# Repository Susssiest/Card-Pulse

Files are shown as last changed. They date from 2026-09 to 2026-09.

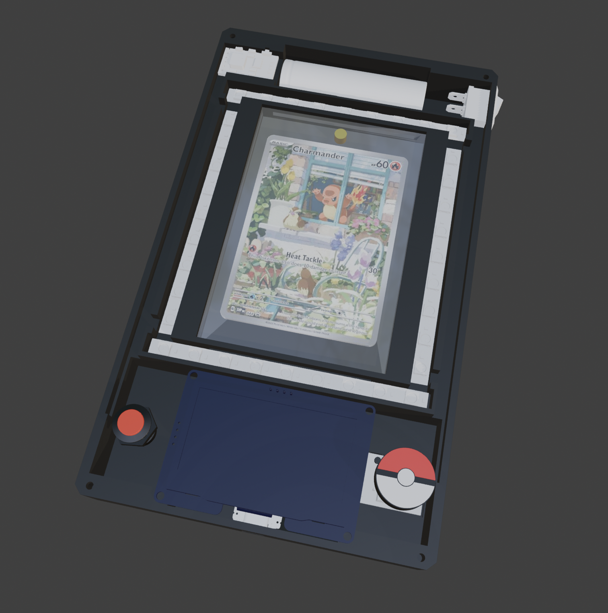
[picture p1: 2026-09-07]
Renders/V2 Internals.png

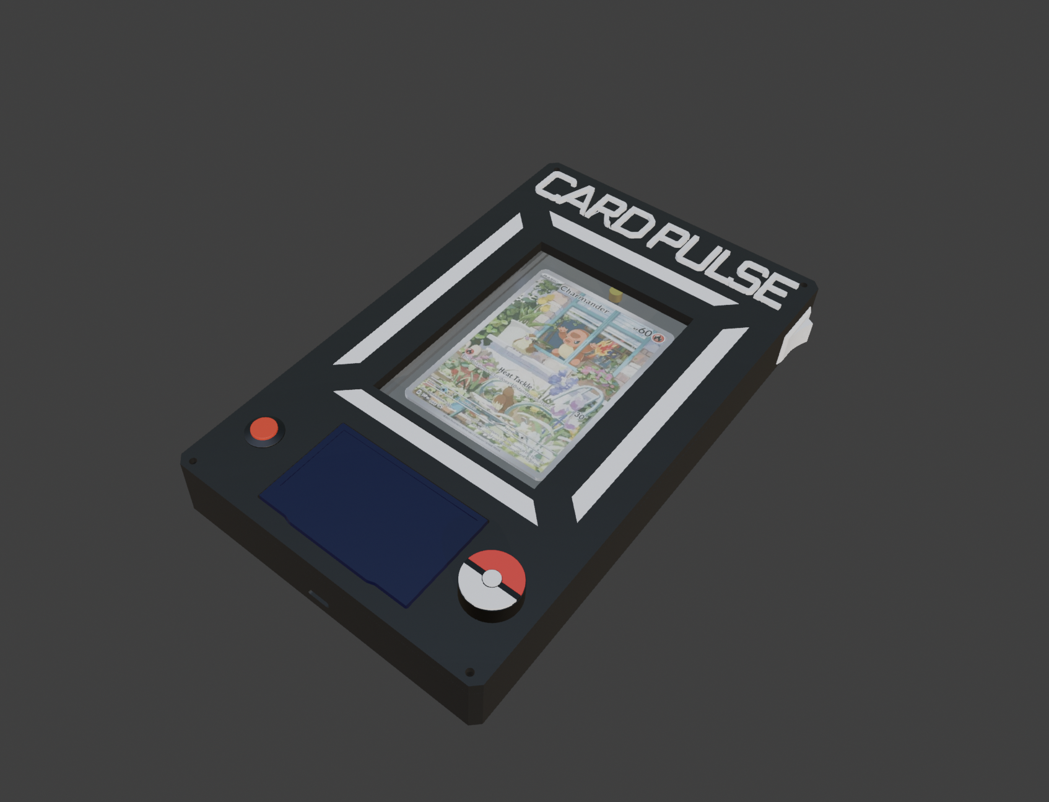
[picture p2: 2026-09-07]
Renders/V2 Render.png

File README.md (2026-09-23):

# Card Pulse

Render

  A little TCG display that can hold a card in a slab that includes a screen to display the value of the card, and a rotary encoder and momentary push button to control the screen. Ws2812bs surround the card in a rectangular frame to surround the card with a underglow and light some transparent filament on the front cover.

## Case Summary

  The card will be inserted into a protective 35pt Toploader, and inserted into the base shell, and then held in place by the top lid, which is screwed in to the base via m3*12 self tapping screws. The case has many different paths and spaces for the different parts: The LEDs have a rectangular cutout around the card, with small holes in the wall separating them to make a underglow effect, but will be also facing upwards, into 3D printed diffusers to have status leds in the lid. The LEDs will have their own control panel/ menu. LEDs will be looped together into one din, gnd, and 5v. The case has a second rectangular hole surrounding the leds, I’m planning on putting all the battery and led wires in it (the battery is above the leds, and therefore the leds are in between the battery and xiao).The wire paths will have an occasional hole in the intersecting wall to provide holes for wires to come through. The card also has a space for a battery, already mentioned above, it sits at the top of the case. It has a space next to it for the 5V boost for leds, and it has a slot to the other side for the power switch.

## Complete List of Parts

1. ESP32S3
2. KY040
3. 12 mm Momentary Push Button
4. 18650 3.7 V Lithium battery
5. 2.42 in Oled Screen
6. 74AHCT14 Level Shifter
7. 5V Boost
8. KCD01
9. Resistor: 330 R
10. Capacitor: 1000uf
11. Capacitor: 0.1uf
12. 22 AWG Wire
13. 26 AWG Wire
14. JST Connectors

## BOM

Screenshot 2026-09-07 at 10 22 27 AM

## Wiring Diagram

Screenshot 2026-09-07 at 10 07 12 AM

## Assembly

https://github.com/user-attachments/assets/116129a6-97be-465f-80bf-904350856c0c

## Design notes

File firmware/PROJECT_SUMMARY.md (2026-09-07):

# CardFrame — Project Summary

## What this is

CardFrame is a battery-powered, Wi-Fi-connected desk display for a single
trading card at a time. It shows the card's name, set/number/variant, and
current market price, plots a price-history graph, and drives an addressable
LED strip for ambient lighting/effects around the frame. All navigation is
done with a rotary encoder (scroll/adjust) and a separate physical button
(select/confirm), with an on-screen keyboard for any text entry (Wi-Fi
passwords, card search). Card and pricing data comes from
[tcgapi.dev](https://tcgapi.dev); when Wi-Fi or the API is unavailable, the
frame falls back to the last cached price or clearly-labeled demo data so it
never freezes or lies about what it's showing.

## Goals

- Run on an ESP32-S3, flashed over its native USB-C port from the Arduino IDE.
- Organize the firmware as a clean, well-commented, modular Arduino sketch
  that's easy to extend later (new screens, a different display, a second
  data source, etc.).
- Make every screen navigable with exactly two physical controls: a KY-040
  rotary encoder (scroll / adjust value) and a separate 12mm momentary push
  button (select / confirm / back). The encoder's own built-in push switch is
  intentionally never used.
- Keep the UI responsive at all times — input, LED animation, and Wi-Fi
  housekeeping all use `millis()`-based non-blocking code, with the one
  unavoidable exception of the tcgapi.dev HTTP calls themselves (bounded to
  an 8-second timeout, triggered only at specific user-initiated moments —
  see `CardFrame.ino`'s top comment for the full rationale).
- Be honest about data provenance: every price and every graph is tagged as
  Live, Cached, or Demo, and the UI never presents mock numbers as real
  market data.

## Core user-facing behavior

**Home screen** — shows the selected card's name, set/number/variant, price,
and last-updated/data-source indicator; a Wi-Fi status icon, an LED-settings
icon, and a card-library icon; and a 7-day (default) price-history graph.
Rotating the encoder moves a highlight between the three icons and the
graph; pressing the button opens whichever is highlighted.

**Card library** — a scrollable list of saved cards plus "Add Card",
"Remove Card" (with a Yes/No confirmation screen), and "Back". Selecting a
card makes it current, returns Home, and refreshes its data.

**Add a card** — an on-screen keyboard (rotary-encoder driven, wraps between
character rows) for typing a search query, which is sent to tcgapi.dev;
results are shown as a scrollable list to pick from and add to the library.
Network errors, empty results, and rate limits are shown as a message
instead of freezing the device.

**Wi-Fi setup** — scans and lists nearby networks, lets you select one and
type its password on the same on-screen keyboard (masked as dots), and shows
connecting/success/failure without blocking the rest of the firmware.
Credentials are saved so the frame reconnects automatically after that.

**Graph settings** — switch the price-history range between 1 day, 7 days,
30 days, 90 days, and 1 year.

**LED settings** — power on/off, brightness, a color, an effect (Solid,
Rainbow, Color Wipe, Breathing, Off), and effect speed, for the WS2812B
strip.

**Offline/demo mode** — if Wi-Fi or tcgapi.dev is unavailable, or a specific
endpoint's response can't be parsed, the frame shows the last cached price
(if any) or a clearly-labeled synthetic "Demo Data"/"Demo History" value
instead of failing silently or showing something misleading.

## Hardware (bill of materials)

| # | Part | Role | Qty |
|---|---|---|-----|
| 1 | ESP32-S3 | Microcontroller, USB-C programming | 1 |
| 2 | WS2812B | Addressable LED strip | 1 |
| 3 | 3.7V 18650 Li-ion | Battery | 1 |
| 4 | MC242GX | 128x64 SSD1309 OLED display, I2C | 1 |
| 5 | KY-040 | Rotary encoder (CLK/DT only; built-in switch unused) | 1 |
| 6 | SW_Push | 12mm momentary push button | 1 |
| 7 | KCD01 | SPST power switch | 1 |
| 8 | (5V boost converter) | Steps battery voltage up to a regulated 5V rail | 1 |
| 9 | 74AHCT14 | Logic-level shifter/buffer for WS2812B data | 1 |
| 10 | 1000µF capacitor | Bulk capacitor on the LED power rail | 1 |
| 11 | 330Ω resistor | Series resistor on the WS2812B data line | 1 |
| 12 | Wire connector kit | General wiring/connectors | 1 |

Full wiring table, power diagram, and the exact 74AHCT14 pin-by-pin plan are
in `README.md`.

## Software architecture

The sketch is split into one file per concern so each piece can be modified,
tested, or swapped independently:

- `CardFrame.ino` — setup()/loop(), the master UI state machine, and the
  handful of moments a blocking tcgapi.dev call is allowed to happen.
- `Types.h` — shared structs/enums (`CardData`, `PriceData`, `UIState`, ...).
- `Config.h` — every pin, timing constant, display setting, and tcgapi.dev
  endpoint/auth placeholder, all in one place.
- `InputManager` — debounced rotary-encoder and button reading.
- `DisplayUI` — the U8g2 display driver plus every screen's drawing and
  navigation logic.
- `Keyboard` — the reusable on-screen keyboard widget (search text and
  masked Wi-Fi passwords both use it).
- `CardLibrary` — saved-card storage (NVS-backed), deliberately decoupled
  from the API and UI so it can later be swapped for SD-card storage, a web
  interface, or cloud sync.
- `WiFiManager` — non-blocking scan/connect state machine wrapping
  ESP32 `WiFi.h`.
- `TcgApiClient` — all HTTPS calls to tcgapi.dev, isolated so its exact
  endpoints/response fields can be updated later without touching any UI
  code. Endpoints whose response schema isn't publicly documented are marked
  `ADAPTER/TODO` and fall back to mock data rather than crashing.
- `LedController` — WS2812B/FastLED driver with non-blocking animation.
- `MockData` — hard-coded demo cards and deterministic mock price/graph
  generators, used both as the initial library seed and as the final
  fallback when the network and cache both come up empty.

## What still needs to be confirmed

The exact `tcgapi.dev` response field names for card details, current price,
and price history are not publicly documented (only `/v1/search` has a
published example response) — those calls are implemented against the
documented paths and authentication, but their JSON parsing is written as an
adapter that tries a couple of plausible field names and falls back to mock
data if the shape doesn't match, so the firmware always compiles and runs
even before those details are pinned down. See the assumptions list in
`README.md` for the complete set of things to double-check before finalizing
pin mapping and the display driver.

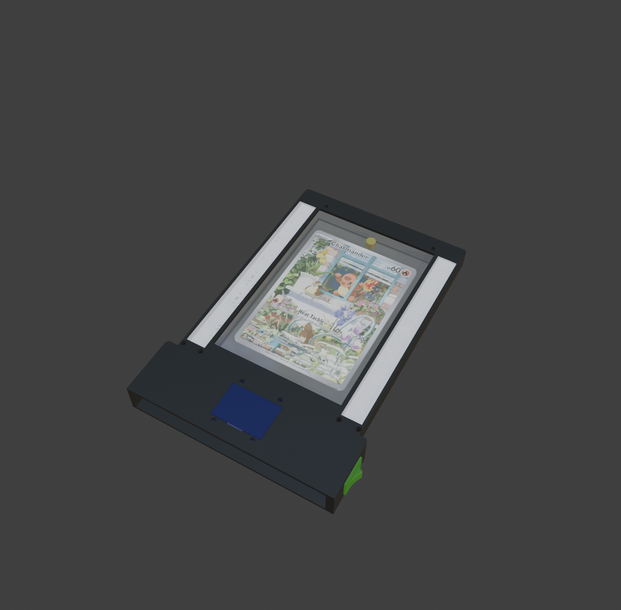
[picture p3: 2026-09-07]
Renders/V1 Render.png

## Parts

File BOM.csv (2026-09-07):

Item | Part Number | Description | Quantity (PART) | Prices | Notes | Seller | LINK | Total
1 | ESP32S3 | Microcontroller | 1 | $16.99 | ESP32S3 specifically | AMAZON | https://www.amazon.com/ESP32S3-2-4GHz-Dual-core-Supported-Efficiency-Interface/dp/B0BYSB66S5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 | $84.16
2 | 3.7V18650 | Battery | 1 | $11.72 | wired | AMAZON | Amazon.com: XINLANTECH 3.7V 2600mAh 18650 Rechargeable Li-ion Battery with Jst XH2.54/2P Connector Plug Wires for DIY Electronics, Toys, Lighting,Bluetooth Devices and More : Health & Household
4 | N.A | Capacitor Kit | 1 | $9.99 |  | AMAZON | https://www.amazon.com/ALLECIN-Electrolytic-Capacitor-Assortment-Kit/dp/B0C1VBXCQM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
5 | N/A | Wire Connectors Kit | 1 | $9.99 |  | AMAZON | https://www.amazon.com/Taiss-Connector-Housing-Connectors-F-066-580PCS/dp/B0BHT1FQGY
6 | SKU:MC242GX | Screen | 1 | $7.56 | white | AMAZON | https://www.aliexpress.us/item/2255799816264653.html?curPageLogUid=IFZZanUI4FB5
7 | KY040 | Rotary Encoder | 1 | $1.34 |  | ALI EXPRESS | https://www.aliexpress.us/item/3256805874306729.html?curPageLogUid=dIarbOQrocIS
8 | SW_Push | 12mm Momentary Push Button | 1 | $1.25 | red | ALI EXPRESS | https://www.aliexpress.us/item/3256804314578211.html?curPageLogUid=THWkP4Y0HGia
9 | KCD01 | SPST Switch | 1 | $1.98 | red | ALI EXPRESS | https://www.aliexpress.us/item/3256804169767079.html?curPageLogUid=kfSuK7F9Npq4
10 | N/A | 5V Boost | 1 | $1.45 |  | ALI EXPRESS | https://www.aliexpress.us/item/3256812360325771.html?curPageLogUid=Ue7Sb1GEffMK
11 | SN74AHCT125N | Level Shifter | 1 | $2.41 |  | ALI EXPRESS | https://www.aliexpress.us/item/3256807469514168.html?curPageLogUid=zjFDIzLuRHGn
12 | N/A | Wire Connectors Kit | 1 | $14.98 |  | ALI EXPRESS | https://www.amazon.com/XALXMAW-Connectors-Splicing-Connector-Stranded/dp/B0B28GQVVG
13 | 22 AWG | Wire: POWER | 1 | $2.60 | RED 10 meters | ALI EXPRESS | https://www.aliexpress.us/item/3256807355811935.html?curPageLogUid=Z52RvaM1nH8V
14 | 26 AWG | WIre: STANDARD | 1 | $1.90 | BLACK 10 meters | ALI EXPRESS | https://www.aliexpress.us/item/3256807355811935.html?curPageLogUid=Z52RvaM1nH8V
15 | R:330 Ω | Resistors | 1 | N/A | DO NOT NEED TO BUY | N/A | https://www.amazon.com/ALLECIN-Values-Resistor-Resistors-Assortment/dp/B0BTP6WYH1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
16 | WS2812B | WS2812B Strip | 1 | N/A | DO NOT NEED TO BUY | N/A | https://www.amazon.com/BTF-LIGHTING-Individual-Addressable-300Pixels-Non-Waterproof/dp/B088BPGMXB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

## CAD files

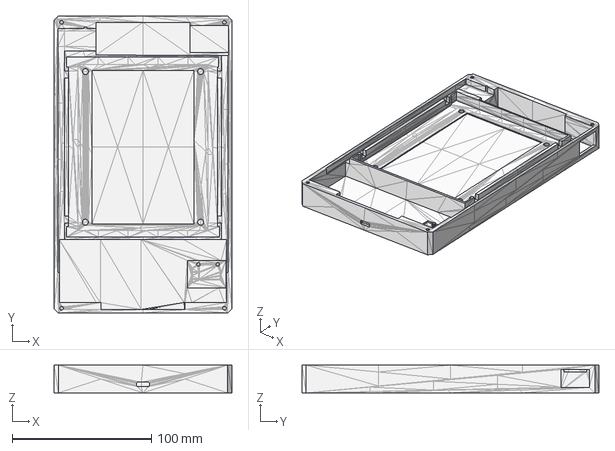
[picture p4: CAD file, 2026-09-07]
CAD/Prints/Main_Shell.step
127.4 x 213.0 x 20.0 mm

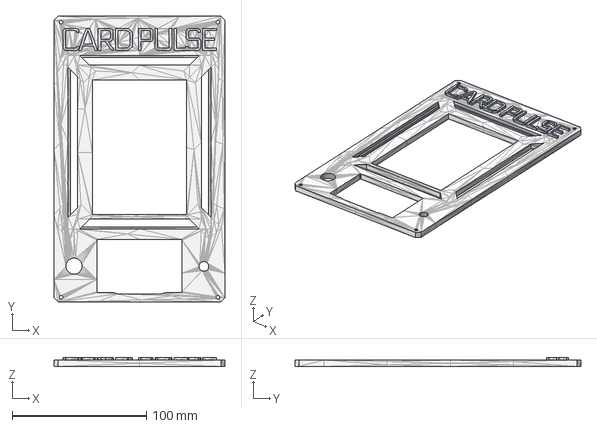
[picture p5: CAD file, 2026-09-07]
CAD/Prints/Card_Lid.step
127.4 x 213.0 x 6.62 mm

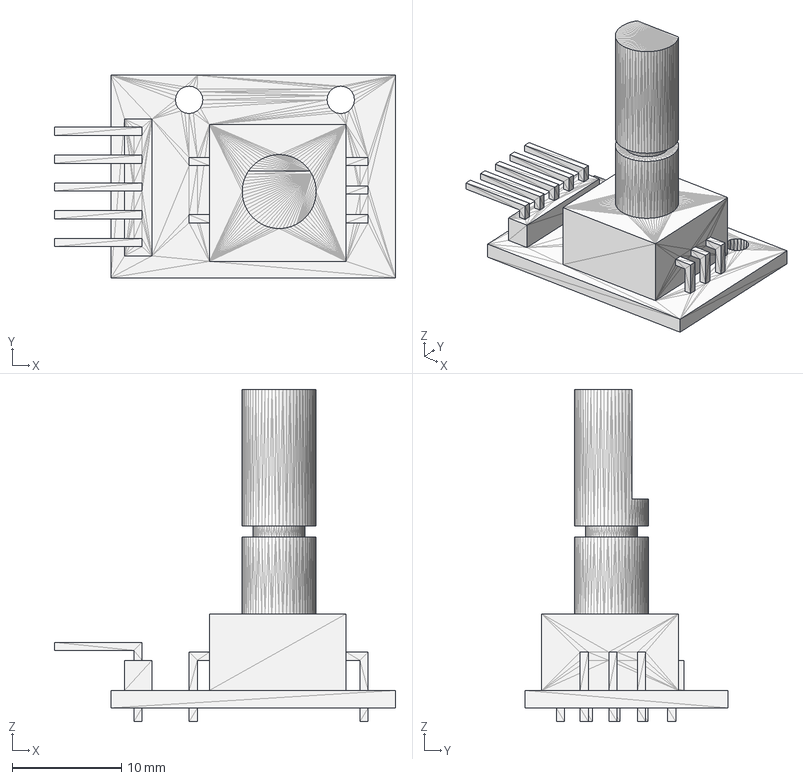
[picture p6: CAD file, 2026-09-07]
CAD/Renders/KY040_Render.step
31.2 x 18.5 x 30.3 mm

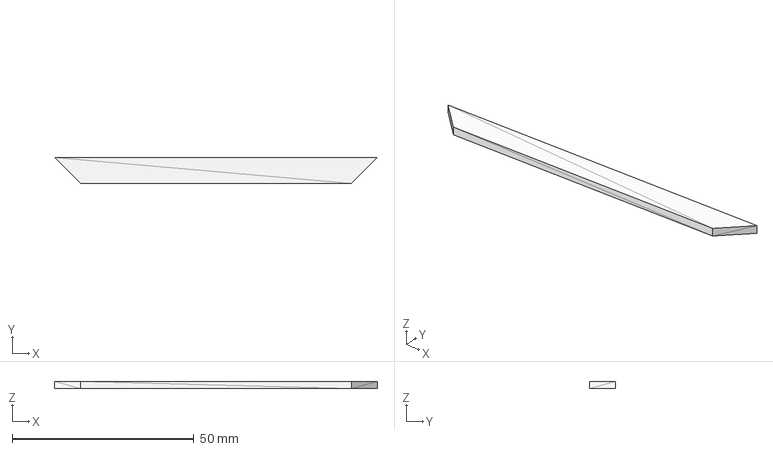
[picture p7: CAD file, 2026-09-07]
CAD/Prints/LED_Cover_1.step
88.8 x 7.15 x 2.00 mm

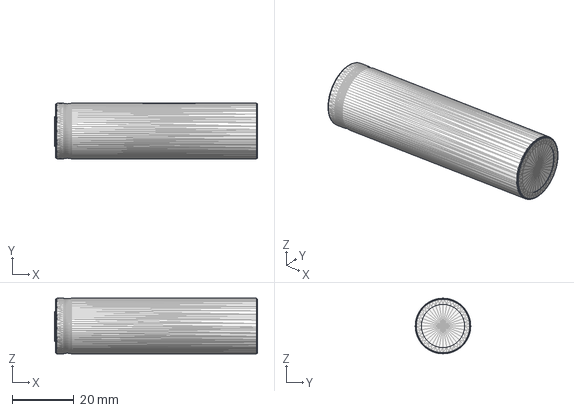
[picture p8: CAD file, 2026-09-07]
CAD/Renders/Battery_Render.step
65.8 x 18.0 x 18.0 mm

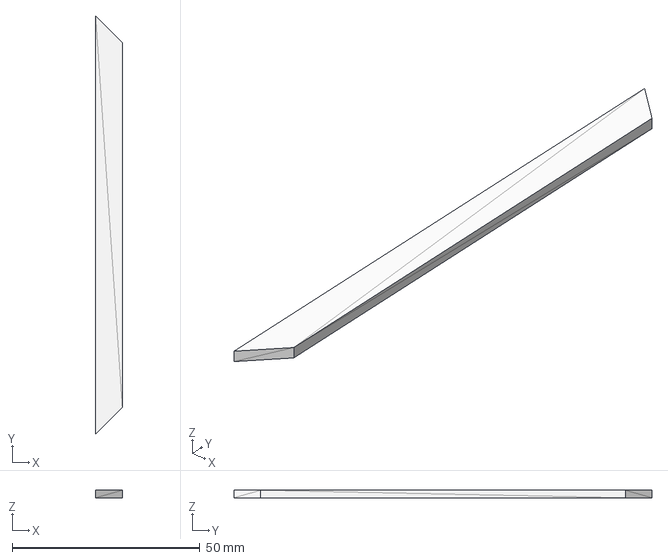
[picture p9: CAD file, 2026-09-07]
CAD/Prints/LED_Cover_3.step
7.11 x 111.4 x 2.00 mm

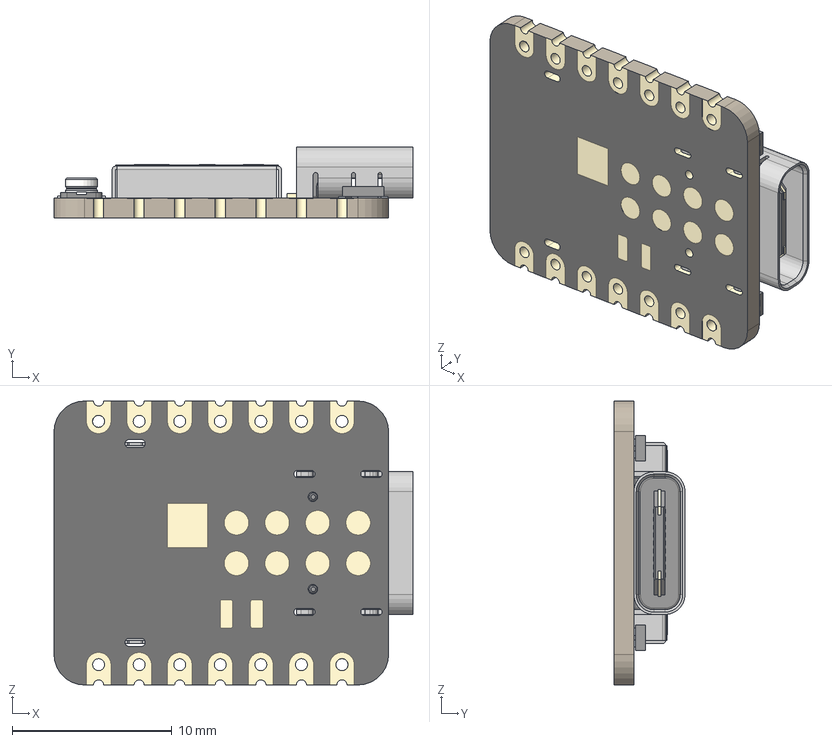
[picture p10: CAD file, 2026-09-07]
CAD/Renders/XIAO-ESP32S3 v3.step
22.5 x 4.46 x 17.8 mm
BOSS-EXTRUDE14_8_
BOSS-EXTRUDE7_4_
BOSS-EXTRUDE7_3_
BOSS-EXTRUDE14_4_
BOSS-EXTRUDE14_2_
BOSS-EXTRUDE14_11_
BOSS-EXTRUDE7_7_
BOSS-EXTRUDE14_9_
BOSS-EXTRUDE14_3_
BOSS-EXTRUDE14_7_
MIRROR2
BOSS-EXTRUDE14_5_
BOSS-EXTRUDE14_12_
BOSS-EXTRUDE7_8_
BOSS-EXTRUDE7_1_
BOSS-EXTRUDE14_10_
BOSS-EXTRUDE7_9_
BOSS-EXTRUDE14_6_
BOSS-EXTRUDE14_1_
BOSS-EXTRUDE7_6_
BOSS-EXTRUDE7_2_
CUT-EXTRUDE5
BOSS-EXTRUDE7_5_
Shield
Pins x 2
U.FL-R-SMT-1_10_ v1

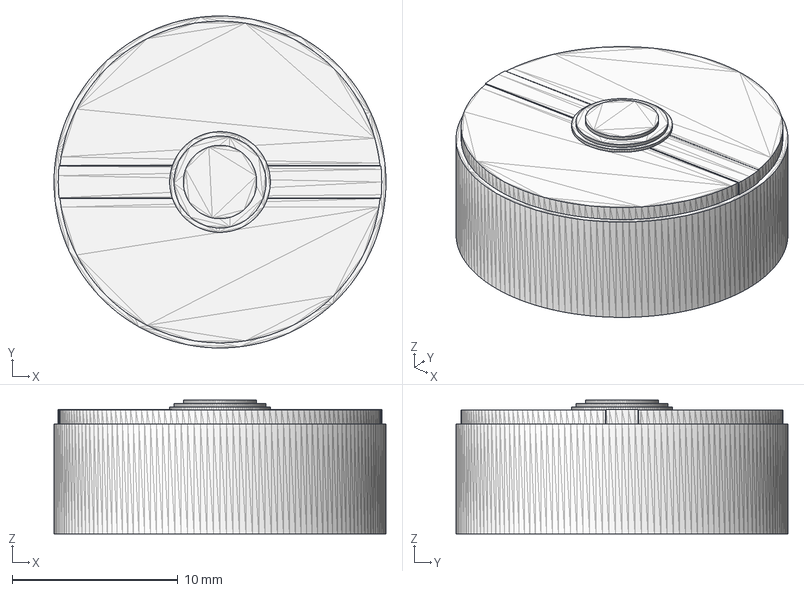
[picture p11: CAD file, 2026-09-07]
CAD/Prints/Pokeball_Knob.step
20.0 x 20.0 x 8.06 mm

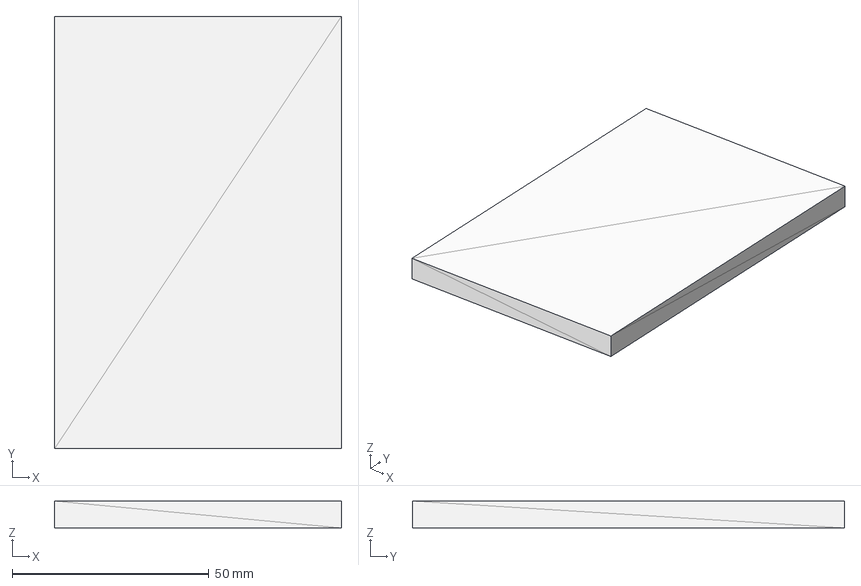
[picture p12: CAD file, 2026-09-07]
CAD/Renders/Card_Render.step
73.0 x 110.0 x 6.86 mm

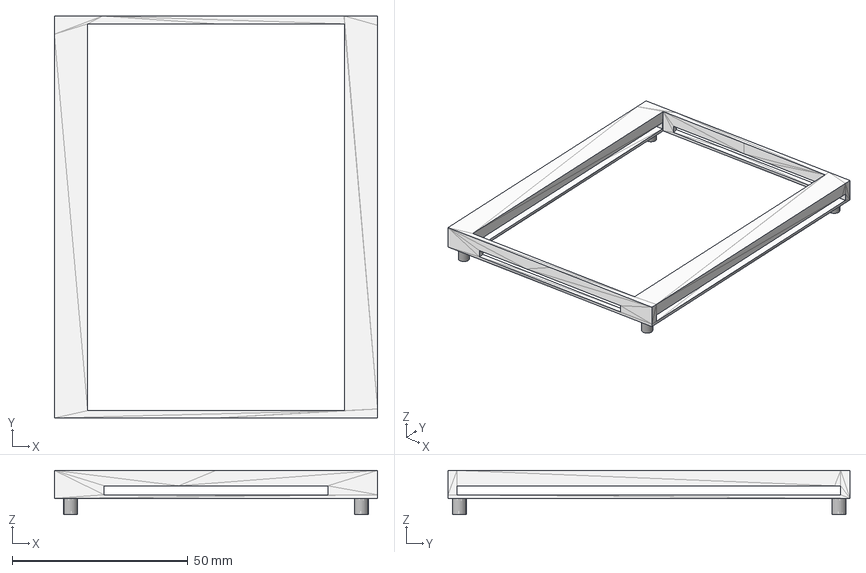
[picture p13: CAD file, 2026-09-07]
CAD/Prints/LED_Underglow.step
92.0 x 114.3 x 12.6 mm

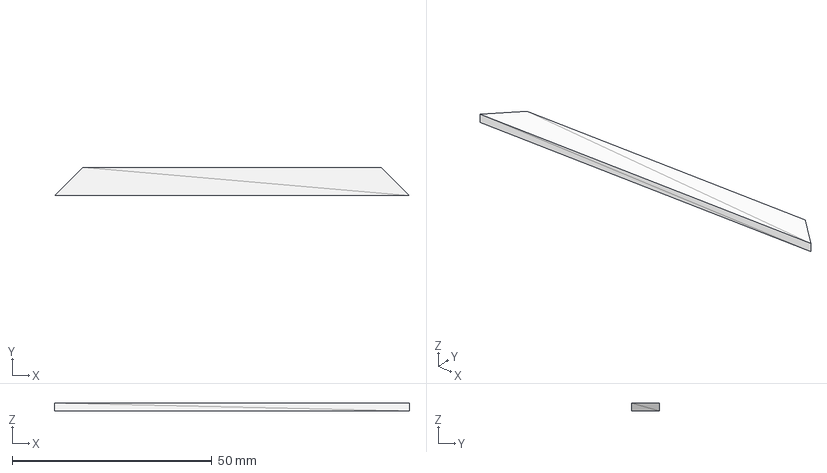
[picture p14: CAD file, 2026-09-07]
CAD/Prints/LED_Cover_4.step
88.8 x 7.09 x 2.00 mm

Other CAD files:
CAD/Prints/LED_Cover_2.step

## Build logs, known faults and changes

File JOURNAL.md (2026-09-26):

# Card Pulse Project BUILD JOURNAL

## Printed Test Version

I printed a test version. The case has a few tolerances that need to be adjusted, and I realized that there were a few non manifold randomly extruding parts of my mesh. Fixed mesh and tolerances in blender by cutting off part that doesnt need to be fixed and applying mirror modifier to delete the messed up side, and then connecting back to good mesh. Reprinting now, hopefully everything works.

Screenshot 2026-09-25 at 1 22 05 PM

**Total time spent: 1 hour, 30 minutes**

## Broke esp32.

Soldered battery to power switch, connected switch to 5v boost, everything was going great. Then I bridged the bat - and + pins on the xiao and then got some solder in d2 accidentally, and then desoldered everything and retried 5 difefrent times, and ended up eventually sepperating the pad from the board and breaking it. Spent too long trying to get solder to stick to the non existent pad and bridge with the traces, gave up after maybe an hour. For some reason when i plugged the xiao into usbc afterwards it heated up and burned my fucking hand. It started smoking and the usbc cable plastic got melty. 16 bucks down the fucking drain.

Screenshot 2026-09-25 at 7 41 35 PM

**Total time spent: 3 hours, 30 minutes**

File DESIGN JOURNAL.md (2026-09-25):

# Card Pulse Project DESIGN JOURNAL

## August 29th: Worked on V1

Started working on the 3d printed frame. Main idea is to have a stand that can plug into a wall outlet and display the led and card price. Going to have leds on the sides, and a oled screen to display the price. Using blender, experiencing the usual problems, non manifold vertices, overlapping vertices, etc. Using ws2812b leds for the bars. I am probably going to use a standard 35pt toploader, but I might make one for psa card slabs. Imported reference card to make it more realistic.

Screenshot 2026-09-04 at 1 29 05 PM

**Total time spent: 3 hours**

## August 31st: Researched and scoured the internet for 3d models of parts.

I spent some time reading articles and forums, as well as talking to Claude for a little. The final parts are going to be:

- KY040
- 12 mm Momentary push button
- Seeed Xiao ESP32C3
- 5V boost
- WS2812B strips
- 3.42 in Oled Screen
- 3.7 V 18650 Lithium Battery
- Wires

  I spent forever scouring the internet for 3D models of the parts, I found most on GrabCad, but a few took forever to find. I also kept on changing my mind between using a KY040 and EC11, but I finally chose the KY040 becuase the pins dont extrude downwards and it is more compact.

Screenshot 2026-09-04 at 6 17 11 PM

**Total time spent: 40 minutes**

## September 2nd: Worked on V2

  I kind of think the frame looks ugly, so I'm restarting. This time I'm thinking of actually having it mobile, and more like a portable case than a frame that sits on your shelf. I will be adding the 3.7 v lithium battery, and a 5v booster, momentary push button, and rotary enocoder into the shell of the case. I feel like it would be cool to make it so you can scroll through different stats on the oled, and maybe even have a wifi choosing menu and led control menu. This complicates my design a lot, so I'm expecting my project to take a little more time than originally expected.

  I spent maybe an hour making the basic case, and then maybe another hour and a half adding functions like underglow, wiring paths, splitting parts, screw holes, etc.Again,ran into lots of blender problems. I love and hate formware at the same time. Oh, I also found a kind of cool but also kind of dorky name for it. "CardPulse". Its pretty freaking dorky lol. I also spent a lot of time redoing stuff and finding dimensions for some of the parts I don't have 3d models for. I also spent a ton of time fixing this one face of the lid, the auto repair tools didn't work so I had to manually do it, I spent like an hour fixing it.

Screenshot 2026-09-04 at 7 14 23 PM

**Total time spent: 4 hours**

## September 4th: Added switch

Realized I didn't have an actual power switch. Added a KCD01, took forever for some reason. Spent maybe 10 minutes finding stl, and an hour - an hour and a half adding the part and hole for it to fit into the case, mainly because face where I added the switch hole get all messed up and I had to spend maybe 40 minutes repairing it. I also changed my mind a bumch about its placement, and blender crashed because I tried perform a weird boolean and I had to restart. I hate blender. I need to learn fusion.

Screenshot 2026-09-04 at 7 47 01 PM

**Total time spent: 1.5 hours**

## September 4th: Imported everything into bambu studio

I'm hoping that the cadding part of the project is done, I imported everything into bambu studio and arranged everything, set infills and wall loops, added strength modifiers, rotated some stuff, and filament mapped everything. Now I can hopefully start working on the code.

Screenshot 2026-09-04 at 8 03 20 PM

**Total time spent: 40 Minutes**

## September 5th: Made wiring diagram.

Spent 2 hours 30 minutes working on the wiring diagram and final selection of parts. I am switching to an ESP23S3, and adding a level shifter for the leds, as well as a resistor, and maybe capacitor. I spent a large amount of my time finding the symbols and footprints, and I had to also make a few myself using the symbol editor. 

Screenshot 2026-09-06 at 7 58 45 AM

**Total time spent: 2.5 hours**

## September 6th: Updated wiring diagram.

Added capacitors, fixed gnd paths with 5v boost, and rechecked schematic. 

Screenshot 2026-09-06 at 1 20 57 PM

**Total time spent: 40 minutes**

## September 6th: Working on code

Spent 3 hours working with perplexity to help me understand code, and then it guided me and generated some of the code. I freaking love computer. I spent maybe 30 minutes finding the perfect api, tcgapi.dev, and then worked with computer on the search engine, and generated a config with a placeholder for my key, and one for myself that has a key. It automatically exported all code to my repo, and write a summary and installation guide. Note: main readme and journal are written by me.

**Total time spent: 3 hours**

Screenshot 2026-09-07 at 8 02 13 AM

## September 7th: Finished BOM and found all final listings

Added final prices, links, sellers, etc in BOM. Will buy from Aliexpress and Amazon. Uploaded BOM to github and put in readme.

Screenshot 2026-09-07 at 10 09 58 AM

**Total time spent: 1 hour**

## September 7th: Finished up all documentation in github

Added renders, polished up readme, rechecked firmware, and updated journal. Compiled files into folders, updated BOM file. I also accidentally reverted the journal to a previus version, and had to rewrite the entries. Copied and pasted forge logs because they didn't get deleted. Also converted all stls to step files, took around 30 minutes.

Screenshot 2026-09-07 at 10 12 14 AM

**Total time spent: 1.5 hours**

## September 8th: animated parts and made a 30 second assembly animation

Animated all the components in blender and recorded the final result, and then converted mov to mp4.

Assembly

**Total time spent: 40 minutes**

## September 15th: Bought everything

Bought all parts, now waiting on amazon and aliexpress. 82 bucks spent with grants, 30 out of pocket.

Screenshot 2026-09-15 at 7 48 31 PM

**Total time spent: 30 minutes**

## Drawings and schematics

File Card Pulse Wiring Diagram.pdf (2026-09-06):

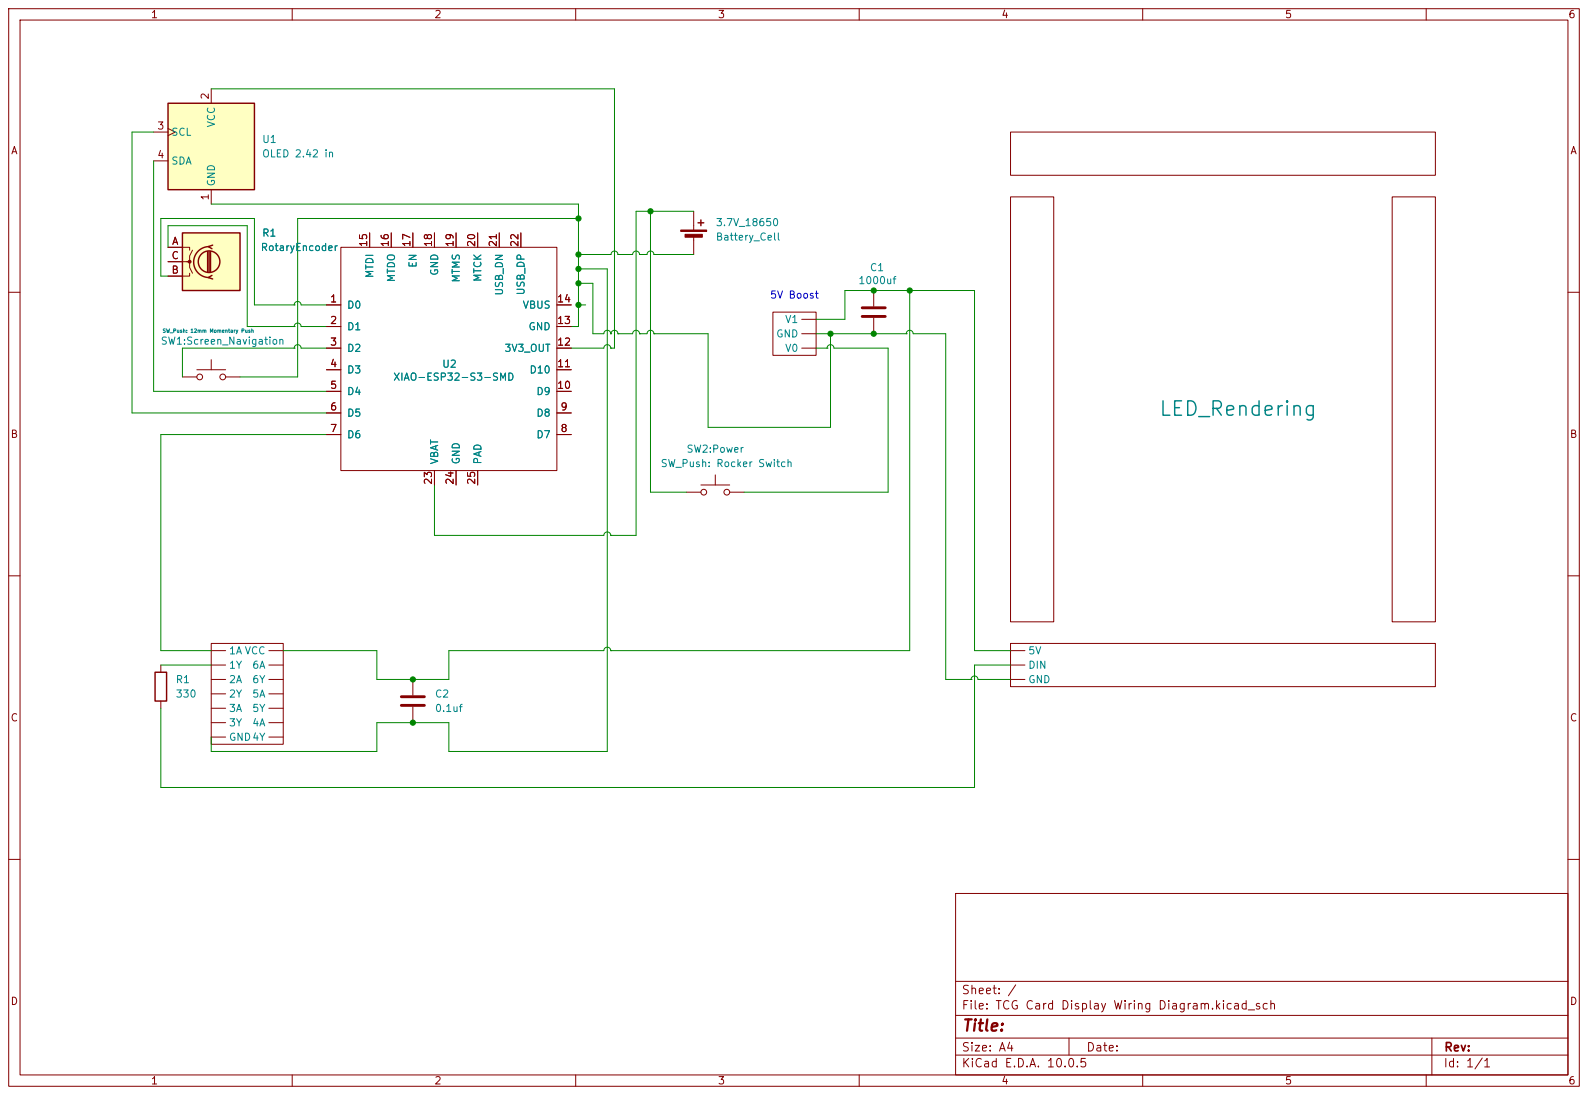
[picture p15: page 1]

Sheet: /
File: TCG Card Display Wiring Diagram.kicad_sch
Title:

Size: A4 | Rev:
KiCad E.D.A. 10.0.5 | Id: 1/1

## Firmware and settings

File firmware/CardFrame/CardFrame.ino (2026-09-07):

/*
 * CardFrame.ino
 * =============================================================================
 * Wi-Fi Trading-Card Display Frame — main sketch (ESP32-S3)
 * =============================================================================
 * This file is deliberately short: it owns setup()/loop(), the single
 * `currentState` variable that drives the whole UI state machine, and the
 * handful of moments where a BLOCKING network call to tcgapi.dev is allowed
 * to happen. Every actual screen, driver, and data module lives in its own
 * .h/.cpp pair (see the tab bar in the Arduino IDE) — read the comment block
 * at the top of each one for what it's responsible for.
 *
 * WHY NETWORK CALLS LIVE HERE AND NOT IN DisplayUI.cpp:
 * TcgApiClient's functions use the synchronous ArduinoHTTPClient library, so
 * each call can block for up to TCGAPI_HTTPS_TIMEOUT_MS (8s) if the network
 * is slow. If DisplayUI called them directly from inside handleInput() (which
 * runs on every single button press), a slow request would freeze button
 * input, encoder input, AND the LED animation for that whole time. Instead,
 * DisplayUI only ever transitions into a lightweight "waiting" state
 * (ADD_CARD_SEARCHING) or exposes what it currently needs
 * (DisplayUI::consumePendingSearch / DisplayUI::currentGraphRange), and this
 * file performs the actual blocking call at one clearly-marked point in
 * loop(), right after the non-blocking input/animation work for that
 * iteration is done. This keeps 100% of the blocking-network-call logic in
 * one auditable place.
 *
 * A fully non-blocking HTTP implementation (manual chunked reads spread
 * across multiple loop() iterations) would remove even this brief pause, but
 * is substantially more code; it's called out as a possible future upgrade
 * in README.md. For a first working version this is a reasonable trade-off:
 * WiFiManager's scan/connect (the other network-ish operations) ARE fully
 * non-blocking already, since those use ESP32 WiFi.h's own async APIs.
 * =============================================================================
 */
#include "Config.h"
#include "Types.h"
#include "InputManager.h"
#include "DisplayUI.h"
#include "CardLibrary.h"
#include "WiFiManager.h"
#include "TcgApiClient.h"
#include "LedController.h"
#include "MockData.h"
#include <Preferences.h>

// -----------------------------------------------------------------------------
// The master state variable. Everything else in the firmware answers the
// question "given this state, what do we draw / what input do we accept?"
// -----------------------------------------------------------------------------
UIState currentState = UIState::HOME;

// Bookkeeping so we know when a fresh tcgapi.dev fetch is actually needed,
// instead of re-fetching on every single loop() iteration.
String lastFetchedCardId = "";
GraphRange lastFetchedRange = GraphRange::DAY_7;
unsigned long lastAutoRefreshMs = 0;
unsigned long lastDrawMs = 0;
unsigned long wifiConnectedScreenSinceMs = 0; // for the "auto-return home" timeout

// =============================================================================
// Small NVS-backed cache for the CURRENT PRICE only (per library slot).
// Price history is cheap to regenerate as a mock curve, but the current
// price is the one thing worth remembering across a power cycle so Home
// doesn't show "Data Unavailable" the moment the frame is unplugged and
// tcgapi.dev is unreachable. Keyed by library slot index (0..MAX_SAVED_CARDS)
// rather than by the (potentially long) tcgapi.dev card id, since ESP32
// Preferences keys are limited to 15 characters.
// =============================================================================
void cachePriceForSlot(int slot, const PriceData& p) {
  Preferences prefs;
  if (!prefs.begin(NVS_NAMESPACE_CACHE, false)) return;
  char kPrice[8], kCur[8], kTs[8];
  snprintf(kPrice, sizeof(kPrice), "p%d", slot);
  snprintf(kCur, sizeof(kCur), "c%d", slot);
  snprintf(kTs, sizeof(kTs), "t%d", slot);
  prefs.putFloat(kPrice, p.price);
  prefs.putString(kCur, p.currency);
  prefs.putULong(kTs, p.lastUpdatedEpoch);
  prefs.end();
}

bool loadCachedPriceForSlot(int slot, PriceData& outPrice) {
  Preferences prefs;
  if (!prefs.begin(NVS_NAMESPACE_CACHE, true)) return false;
  char kPrice[8];
  snprintf(kPrice, sizeof(kPrice), "p%d", slot);
  if (!prefs.isKey(kPrice)) { prefs.end(); return false; }
  outPrice.price = prefs.getFloat(kPrice, 0.0f);
  char kCur[8], kTs[8];
  snprintf(kCur, sizeof(kCur), "c%d", slot);
  snprintf(kTs, sizeof(kTs), "t%d", slot);
  String cur = prefs.getString(kCur, "USD");
  strncpy(outPrice.currency, cur.c_str(), sizeof(outPrice.currency) - 1);
  outPrice.currency[sizeof(outPrice.currency) - 1] = '\0';
  outPrice.lastUpdatedEpoch = prefs.getULong(kTs, 0);
  outPrice.valid = true;
  prefs.end();
  return true;
}

// =============================================================================
// The one function that talks to tcgapi.dev for the currently selected card.
// Called: right after boot, right after the user picks a different card,
// right after the user changes the graph range, and periodically every
// API_REFRESH_INTERVAL_MS. Falls back live -> cached (NVS) -> mock, and tags
// the result with the correct DataSource so the UI never lies about it.
// =============================================================================
void refreshCurrentCardData() {
  const CardData& card = CardLibrary::selectedCard();
  if (!card.valid) {
    PriceData empty; // valid=false
    PricePoint noPoints[1];
    DisplayUI::setCurrentPrice(empty);
    DisplayUI::setCurrentGraph(noPoints, 0, DisplayUI::currentGraphRange(), DataSource::DEMO);
    return;
  }

  int slot = CardLibrary::selectedIndex();
  GraphRange range = DisplayUI::currentGraphRange();
  bool wifiUp = (WiFiManager::status() == WifiStatus::CONNECTED);

  // ---- Current price ----
  PriceData price;
  bool gotLive = wifiUp && TcgApiClient::fetchCurrentPrice(card.cardId, price);
  if (gotLive) {
    price.source = DataSource::LIVE;
    price.valid = true;
    cachePriceForSlot(slot, price);
  } else if (loadCachedPriceForSlot(slot, price)) {
    price.source = DataSource::CACHED;
  } else {
    price = MockData::getMockPrice(card.cardId);
    price.source = DataSource::DEMO;
  }
  DisplayUI::setCurrentPrice(price);

  // ---- Price history ----
  PricePoint points[MAX_GRAPH_POINTS];
  int count = 0;
  bool gotHistory = wifiUp && TcgApiClient::fetchPriceHistory(card.cardId, range, points, MAX_GRAPH_POINTS, count);
  DataSource graphSource;
  if (gotHistory && count >= 2) {
    graphSource = DataSource::LIVE;
  } else {
    // tcgapi.dev history requires a paid tier and/or the endpoint's schema
    // isn't confirmed yet (see TcgApiClient.cpp ADAPTER notes) -> fall back
    // to a clearly-labeled synthetic curve rather than pretending it's real.
    count = MockData::getMockHistory(card.cardId, range, points, MAX_GRAPH_POINTS);
    graphSource = DataSource::DEMO;
  }
  DisplayUI::setCurrentGraph(points, count, range, graphSource);

  lastFetchedCardId = card.cardId;
  lastFetchedRange = range;
  lastAutoRefreshMs = millis();
}

// =============================================================================
// setup()
// =============================================================================
void setup() {
#if SERIAL_DEBUG_ENABLED
  Serial.begin(115200);
  delay(200); // brief pause so the first log lines aren't lost on some boards
  DBG_PRINTLN("\n[CardFrame] Booting...");
#endif

  InputManager::begin();
  LedController::begin();
  CardLibrary::begin();      // loads saved cards from NVS, or seeds demo cards
  WiFiManager::begin();      // attempts auto-connect using saved credentials
  TcgApiClient::begin();
  DisplayUI::begin();        // brings up the MC242GX/SSD1309 display over I2C

  DisplayUI::onEnterState(currentState);

  // Populate Home with *something* immediately (cached or mock), so the
  // screen never shows an empty flash while the first live fetch is pending.
  refreshCurrentCardData();
}

// =============================================================================
// loop()
// =============================================================================
void loop() {
  unsigned long now = millis();

  // ---- 1. Non-blocking input sampling (cheap, every iteration) ----
  InputManager::update();
  int steps = InputManager::takeEncoderSteps();
  bool pressed = InputManager::wasButtonPressed();

  // ---- 2. Let the active screen react to input, possibly changing state ----
  UIState nextState = DisplayUI::handleInput(currentState, steps, pressed);
  if (nextState != currentState) {
    UIState previousState = currentState;
    currentState = nextState;
    DisplayUI::onEnterState(currentState);

    // Leaving the Card Library having selected a *different* card, or
    // leaving Graph Range Select having applied a *different* range, both
    // land back on HOME — refresh data right away rather than waiting for
    // the periodic timer.
    bool cardChanged = (CardLibrary::selectedCard().cardId != lastFetchedCardId);
    bool rangeChanged = (DisplayUI::currentGraphRange() != lastFetchedRange);
    if (currentState == UIState::HOME && (previousState == UIState::CARD_LIBRARY ||
                                           previousState == UIState::GRAPH_RANGE_SELECT ||
                                           previousState == UIState::ADD_CARD_RESULTS) &&
        (cardChanged || rangeChanged)) {
      refreshCurrentCardData();
    }
    if (currentState == UIState::WIFI_CONNECTING) {
      wifiConnectedScreenSinceMs = 0; // reset; set once CONNECTED is observed below
    }
  }

  // ---- 3. The ONE place a blocking tcgapi.dev search call is allowed ----
  if (currentState == UIState::ADD_CARD_SEARCHING) {
    String query;
    if (DisplayUI::consumePendingSearch(query)) {
      CardResult results[MAX_SEARCH_RESULTS];
      int resultCount = 0;
      bool ok = false;
      const char* statusMsg = "";
      if (WiFiManager::status() != WifiStatus::CONNECTED) {
        statusMsg = "No Wi-Fi connection";
      } else {
        ok = TcgApiClient::searchCards(query, results, MAX_SEARCH_RESULTS, resultCount);
        if (!ok) {
          int http = TcgApiClient::lastHttpStatus();
          // Status codes confirmed against the live API on 2026-09-06:
          // 402 = missing/invalid key (tcgapi.dev's x402 payment challenge,
          // used in place of a plain 401), 403 = valid key but this
          // endpoint needs a higher paid tier, 404 = not found, 429 =
          // conventional rate-limit status (daily cap is 100 requests on
          // the free tier; not directly observed during testing but
          // handled defensively since it's easy to hit).
          if (http == 429) statusMsg = "Rate limited - try later";
          else if (http == 402) statusMsg = "Invalid or missing API key";
          else if (http == 403) statusMsg = "Needs a higher API tier";
          else if (http == 404) statusMsg = "Not found";
          else if (http <= 0) statusMsg = "Network error";
          else statusMsg = "tcgapi.dev error";
        }
      }
      DisplayUI::setSearchResults(results, resultCount, ok, statusMsg);
      currentState = UIState::ADD_CARD_RESULTS;
      DisplayUI::onEnterState(currentState);
    }
  }

  // ---- 4. Auto-advance out of the Wi-Fi connecting screen on success ----
  if (currentState == UIState::WIFI_CONNECTING && WiFiManager::status() == WifiStatus::CONNECTED) {
    if (wifiConnectedScreenSinceMs == 0) wifiConnectedScreenSinceMs = now;
    if (now - wifiConnectedScreenSinceMs > 1200) { // let the user see "Connected!" briefly
      currentState = UIState::HOME;
      DisplayUI::onEnterState(currentState);
      refreshCurrentCardData(); // Wi-Fi just came up -> worth a fresh fetch
    }
  }

  // ---- 5. Periodic background refresh (respects API_REFRESH_INTERVAL_MS) ----
  if (currentState == UIState::HOME && (now - lastAutoRefreshMs) >= API_REFRESH_INTERVAL_MS) {
    refreshCurrentCardData();
  }

  // ---- 6. Always-on non-blocking background work ----
  WiFiManager::update();
  LedController::update();

  // ---- 7. Throttled redraw ----
  if (now - lastDrawMs >= DISPLAY_FRAME_INTERVAL_MS) {
    DisplayUI::draw(currentState);
    lastDrawMs = now;
  }
}

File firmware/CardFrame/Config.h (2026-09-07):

/*
 * Config.h
 * ---------------------------------------------------------------------------
 * SINGLE SOURCE OF TRUTH for hardware pins, the display driver, the
 * tcgapi.dev connection, timing constants, and LED defaults.
 *
 * If you rewire something, change the pin here — never hunt through the
 * other .cpp files for a hard-coded GPIO number. Every other file includes
 * this one and uses these names.
 * ---------------------------------------------------------------------------
 */
#pragma once

// #############################################################################
// # 1. DISPLAY CONFIGURATION  — SKU: MC242GX
// #############################################################################
// CONFIRMED from the manufacturer (LCDWIKI/QDtech) specification for
// SKU MC242GX: 2.42" monochrome OLED, 128x64 pixels, SSD1309 driver IC,
// I2C ("IIC") interface, 5-pin header (GND, VCC, SCL, SDA, RES-unpopulated),
// runs from 3.3V-5V. Two I2C addresses are available depending on how the
// board's address-select resistor is soldered from the factory:
//   solder pad -> 0x78 (write byte) = 7-bit address 0x3C  (MOST COMMON / default)
//   solder pad -> 0x7A (write byte) = 7-bit address 0x3D
// Source: LCDWIKI MC242GX specification & user manual (lcdwiki.com/res/MC242GX).
//
// >>> ASSUMPTION TO CONFIRM: if your specific board came with the address
// >>> pad soldered to 0x7A, change DISPLAY_I2C_ADDR below to 0x3D. Most units
// >>> ship as 0x3C. If the screen stays blank, this is the first thing to check.
#define DISPLAY_DRIVER_SSD1309      1     // driver IC confirmed by datasheet
#define DISPLAY_WIDTH_PX            128
#define DISPLAY_HEIGHT_PX           64
#define DISPLAY_I2C_ADDR            0x3C  // 7-bit address (0x78 >> 1)
#define DISPLAY_USE_I2C             1     // MC242GX in this BOM is the IIC variant
#define DISPLAY_RESET_PIN           -1    // RES pin is unpopulated on MC242GX by
                                          // default; -1 tells U8g2 "no reset pin,
                                          // use software reset". Solder RES and
                                          // set a real GPIO here if you need it.

// #############################################################################
// # 2. GPIO PIN MAP  (ESP32-S3, generic dev board with USB-C)
// #############################################################################
// >>> ASSUMPTION TO CONFIRM: these are sensible, commonly-free GPIOs on most
// >>> ESP32-S3 dev boards (DevKitC-1 style). GPIO0, 45, 46 are strapping pins
// >>> (boot mode) and GPIO19/20 are the native USB D-/D+ on most boards —
// >>> all four are intentionally AVOIDED below. If your specific board (XIAO
// >>> ESP32S3, ESP32-S3-Zero, etc.) reserves different pins, just edit the
// >>> numbers here; nothing else in the firmware needs to change.

// --- I2C bus (shared by the MC242GX OLED) ---
#define PIN_I2C_SDA        8
#define PIN_I2C_SCL        9

// --- KY-040 rotary encoder (quadrature outputs only — see note below) ---
#define PIN_ENCODER_CLK    4   // KY-040 "CLK" output (A phase)
#define PIN_ENCODER_DT     5   // KY-040 "DT"  output (B phase)
// NOTE: The KY-040 module's own built-in push switch (its "SW" pin) is
// intentionally NOT wired/read anywhere in this firmware, per project spec.
// All select/confirm/back actions use the separate 12mm momentary button below.

// --- Separate 12mm momentary push button (SW_Push) ---
#define PIN_BUTTON_SELECT  6   // OK / Select / Confirm / Save / Connect / Back

// --- WS2812B data line (goes through the 74AHCT14 level shifter, see the
//     wiring plan in README.md before the LED strip) ---
#define PIN_LED_DATA       7

// #############################################################################
// # 3. WS2812B LED STRIP CONFIGURATION
// #############################################################################
// >>> ASSUMPTION TO CONFIRM: set this to the ACTUAL number of LEDs on your
// >>> strip before flashing. Everything else (current budget math in
// >>> README.md, animation timing) is derived from this constant.
#define LED_COUNT          24
#define LED_COLOR_ORDER    GRB   // WS2812B is almost always GRB; swap if colors
                                  // look wrong (e.g. red shows as green)
#define LED_DEFAULT_BRIGHTNESS 128   // 0-255
#define LED_MAX_BRIGHTNESS      255  // hard ceiling exposed in the UI
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

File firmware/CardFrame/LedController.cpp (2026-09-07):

/*
 * LedController.cpp
 * ---------------------------------------------------------------------------
 * IMPORTANT WIRING NOTE (see README.md for the full explanation):
 * PIN_LED_DATA (an ESP32-S3 3.3V GPIO) drives the 74AHCT14 buffer/inverter,
 * whose OUTPUT (already boosted to a clean 5V logic level) feeds the 330ohm
 * series resistor and then the first WS2812B's DIN pin. The strip's 5V and
 * GND come straight from the boost converter, NOT from the ESP32-S3.
 * ---------------------------------------------------------------------------
 */
#include "LedController.h"
#include "Config.h"
#include <FastLED.h>
#include <Preferences.h>

namespace LedController {

namespace {
  CRGB leds[LED_COUNT];
  Preferences prefs;

  bool powerOn = true;
  uint8_t brightness = LED_DEFAULT_BRIGHTNESS;
  uint8_t colorR = 255, colorG = 80, colorB = 0; // warm amber default
  LedEffect effect = LedEffect::SOLID;
  uint8_t speed = 128;

  unsigned long lastStepMs = 0;
  uint16_t animPhase = 0; // generic animation counter, meaning depends on effect

  // ---- Effect renderers -----------------------------------------------
  // Each is a pure function of `animPhase` so effects stay perfectly
  // non-blocking: no delay() anywhere in this file.

  void renderSolid() {
    fill_solid(leds, LED_COUNT, CRGB(colorR, colorG, colorB));
  }

  void renderRainbow() {
    fill_rainbow(leds, LED_COUNT, animPhase & 0xFF, 256 / LED_COUNT + 1);
  }

  void renderColorWipe() {
    // Wipes the chosen color down the strip, then wipes back off, and repeats.
    uint16_t cycle = LED_COUNT * 2;
    uint16_t pos = animPhase % cycle;
    for (int i = 0; i < LED_COUNT; i++) {
      bool lit = (pos < LED_COUNT) ? (i <= pos) : (i > (pos - LED_COUNT));
      leds[i] = lit ? CRGB(colorR, colorG, colorB) : CRGB::Black;
    }
  }

  void renderBreathing() {
    // Sine-based breathing looks smoother than a linear ramp.
    uint8_t level = beatsin8((speed / 8) + 1, 10, 255, 0, 0);
    fill_solid(leds, LED_COUNT, CRGB(colorR, colorG, colorB));
    nscale8(leds, LED_COUNT, level);
  }

  void renderOff() {
    fill_solid(leds, LED_COUNT, CRGB::Black);
  }
} // anonymous namespace

void begin() {
  FastLED.addLeds<WS2812B, PIN_LED_DATA, LED_COLOR_ORDER>(leds, LED_COUNT);
  FastLED.setBrightness(brightness);
  loadSettings();
}

void update() {
  unsigned long now = millis();
  if (now - lastStepMs < LED_ANIM_INTERVAL_MS) return;
  lastStepMs = now;

  if (!powerOn || effect == LedEffect::OFF) {
    renderOff();
    FastLED.show();
    return;
  }

  // Advance the phase counter at a rate controlled by `speed`. Mapping speed
  // (0-255) to an increment keeps every effect's perceived pace consistent.
  uint16_t increment = 1 + (speed / 16);
  animPhase += increment;

  switch (effect) {
    case LedEffect::SOLID:      renderSolid();     break;
    case LedEffect::RAINBOW:    renderRainbow();   break;
    case LedEffect::COLOR_WIPE: renderColorWipe(); break;
    case LedEffect::BREATHING:  renderBreathing(); break;
    default:                    renderOff();       break;
  }

  FastLED.setBrightness(brightness);
  FastLED.show();
}

void setPower(bool on) { powerOn = on; }
bool getPower() { return powerOn; }

void setBrightness(uint8_t b) { brightness = b; }
uint8_t getBrightness() { return brightness; }

void setColor(uint8_t r, uint8_t g, uint8_t b) { colorR = r; colorG = g; colorB = b; }
void getColor(uint8_t &r, uint8_t &g, uint8_t &b) { r = colorR; g = colorG; b = colorB; }

void setEffect(LedEffect e) { effect = e; animPhase = 0; }
LedEffect getEffect() { return effect; }

void setSpeed(uint8_t s) { speed = s; }
uint8_t getSpeed() { return speed; }

void loadSettings() {
  prefs.begin(NVS_NAMESPACE_LED, /*readOnly=*/true);
  powerOn    = prefs.getBool("power", true);
  brightness = prefs.getUChar("bright", LED_DEFAULT_BRIGHTNESS);
  colorR     = prefs.getUChar("r", colorR);
  colorG     = prefs.getUChar("g", colorG);
  colorB     = prefs.getUChar("b", colorB);
  effect     = static_cast<LedEffect>(prefs.getUChar("effect", static_cast<uint8_t>(LedEffect::SOLID)));
  speed      = prefs.getUChar("speed", 128);
  prefs.end();
}

void saveSettings() {
  prefs.begin(NVS_NAMESPACE_LED, /*readOnly=*/false);
  prefs.putBool("power", powerOn);
  prefs.putUChar("bright", brightness);
  prefs.putUChar("r", colorR);
  prefs.putUChar("g", colorG);
  prefs.putUChar("b", colorB);
  prefs.putUChar("effect", static_cast<uint8_t>(effect));
  prefs.putUChar("speed", speed);
  prefs.end();
}

} // namespace LedController

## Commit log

2026-09-04 Add journal entries for project sessions
    Documented project sessions for 3D printed frame development, detailing design ideas and challenges faced during the process.
2026-09-04 Document progress on V1 and time spent
    Added details about work on the 3D printed frame and project progress.
2026-09-04 Document electronic TCG card display project details
    Added details about the electronic TCG card display project, including session information and progress on the 3D printed frame.
2026-09-05 Revise JOURNAL.md with project updates
    Updated project details and time spent on the case design.
2026-09-05 Update JOURNAL.md with switch installation details
    Documented the addition of a power switch and time spent on the task.
2026-09-05 Revise project description for portable case design
    Updated project details and design considerations for the portable case, including components and challenges faced during development.
2026-09-06 Add case summary and details to README
    Added a case summary section detailing the card insertion and LED arrangements, along with battery and wiring considerations.
2026-09-06 Fix grammar and clarity in README description
    Corrected grammatical errors and improved clarity in the description of the case design.
2026-09-06 Update JOURNAL.md with September 5th entry
    Documented work on wiring diagram and part selection.
2026-09-06 Revise wiring diagram entry for September 5th
    Updated the wiring diagram entry with new component details and an image.
2026-09-07 Add CardFrame ESP32-S3 firmware
    Complete Arduino IDE firmware for the Card Pulse display: menu/state-machine
    architecture, KY-040 encoder for navigation, separate 12mm button for
    select/confirm/back, Home/Library/Add-Card/WiFi/Graph/LED-settings screens,
    and a tcgapi.dev client with schemas confirmed against the live API
    (search, card details, prices, price history). Includes a project summary
    and a full build/flash README (wiring table, power diagram, 74AHCT14
    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
2026-09-07 Fix sketch folder structure
    Arduino IDE requires the sketch folder name to match its main .ino file
    (firmware/CardFrame/CardFrame.ino), not a loose file directly under
    firmware/. Verified it still compiles from the corrected path.
    [CardFrame.ino, Config.h, DisplayUI.cpp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]
2026-09-07 Expand case summary with additional component details
    Added details about components and wiring for the case design.
2026-09-07 Rename TCG Frame BOM - Sheet1.csv to BOM.csv
    [BOM.csv]
2026-09-07 Revise BOM.csv with updated item information
    Updated BOM.csv to reflect new item details, prices, and links.
    [BOM.csv]
2026-09-07 Update JOURNAL.md with BOM completion details
    Documented final prices, links, and sellers in BOM. Uploaded BOM to GitHub and updated README.
2026-09-07 replacing files
    [BOM.csv]
2026-09-07 Update README with new components and wiring diagram
    Added additional components and wiring diagram to README.
2026-09-07 Update case summary with detailed design specifications
    Clarified the case design details, including screw type and wire management.
2026-09-07 Update BOM and documentation for September 7th
    Added final prices, links, and sellers to BOM. Updated documentation and journal entries, including images and time spent.
2026-09-07 Added cad
    [5V_Boost_Render.stl, Battery_Render.stl, Card_Lid.stl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]
2026-09-07 replacing stls with steps
    [Card_Lid.step, Card_Lid.stl, LED_Cover_1.step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]
2026-09-08 Add Card Pulse schematic file
    [Card Pulse.sch]
2026-09-08 Document September 8th animation work in JOURNAL.md
    Added details about animated parts and assembly animation created on September 8th.
2026-09-23 Add assembly section to README
    Added assembly section with a link to resources.
